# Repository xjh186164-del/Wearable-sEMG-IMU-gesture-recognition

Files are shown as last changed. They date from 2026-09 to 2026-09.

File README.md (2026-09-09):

# Wearable sEMG--IMU Gesture Recognition System

This repository contains the hardware designs, embedded firmware, host
software, accepted recordings and trained model for a battery-powered wearable
gesture-recognition prototype. The system combines eight-channel surface
electromyography (sEMG) with six-axis inertial sensing and transmits both sensor
streams to a host computer using Bluetooth Low Energy (BLE).

The project was developed as an engineering research prototype. It is not a
medical device and must not be used for diagnosis, clinical monitoring or
safety-critical control.

## System overview

The wearable system consists of:

- a custom four-layer ADS1298-based acquisition PCB;
- an LSM6DSOX three-axis accelerometer and three-axis gyroscope;
- an ESP32-C3 microcontroller and BLE link;
- eight bipolar electrode modules and a separate right-leg-drive electrode;
- independently adjustable electrode, right-leg-drive and electronics straps;
- a rechargeable LP603449 lithium-polymer battery;
- MATLAB acquisition, filtering, visualisation and recording software;
- a Python dual-branch convolutional neural network for real-time recognition.

The production firmware samples sEMG at 500 Hz and the IMU at 104 Hz. MATLAB
constructs temporally corresponding 0.5 s windows, and the Python model combines
the two sensor modalities using class-dependent trainable late fusion.

## Reported results

Twenty-one accepted guided-recording sessions provided approximately 62.98
minutes of simultaneous sensor data. The derived dataset contains 12,936 paired
windows representing eight classes. A session-level split assigned 14 sessions
to training, three to validation and four to held-out testing.

On 2,464 held-out test windows, the selected personalised model achieved:

| Metric | Result |
|---|---:|
| Accuracy | 99.68% |
| Balanced accuracy | 99.55% |
| Macro-F1 | 99.64% |

A controlled ablation study subsequently retrained five model variants using
the same session split and three fixed random seeds (20260821--20260823):

| Model variant | Test Macro-F1, mean +/- SD | Target-trial accuracy |
|---|---:|---:|
| sEMG only | 85.33 +/- 2.89% | 91.67% |
| IMU only | 94.09 +/- 0.96% | 98.21% |
| Fixed 50:50 fusion | 99.64 +/- 0.34% | 100.00% |
| Trainable fusion, neutral initialisation | 99.65 +/- 0.32% | 100.00% |
| Trainable fusion, physics-informed initialisation | 99.67 +/- 0.03% | 100.00% |

The experiment verifies the benefit of combining the two modalities for this
gesture set. It does not establish a meaningful accuracy advantage of learned
class-dependent fusion over fixed 50:50 fusion on this dataset. The
physics-informed initialisation is therefore treated as an optimisation prior,
not as evidence that the model independently discovered sensor importance.

These measurements demonstrate personalised recognition for one physical
participant under the tested conditions. They do not establish equivalent
performance for unseen users, alternative electrode placements or uncontrolled
operating environments. Successive 0.5 s evaluation windows advance by 0.1 s,
so the aggregate window predictions overlap by 80% and are not independent
trials; session-level and target-trial results are included alongside them.

## Repository structure

```text
.
├── Hardware/
│   ├── Enclosure and Armband/     # Editable Fusion 360 mechanical designs
│   └── Schematic and PCB/         # EasyEDA project, schematic, BOM/CPL and Gerber archive
├── Software/
│   ├── Firmware/                  # Production ESP32-C3 firmware only
│   ├── MATLAB/                    # BLE acquisition, filtering and live display
│   ├── Python/                    # Dataset, training and inference package
│   └── README.md
├── Data/
│   ├── captures/                  # 21 accepted six-artifact sessions
│   ├── datasets/                  # Paired 0.5 s window dataset and manifest
│   ├── training_runs/             # Selected checkpoint and controlled ablations
│   ├── realtime_configs/          # Validation-selected decision configuration
│   ├── checksums.sha256
│   └── README.md
├── .gitattributes
├── .gitignore
└── README.md
```

Detailed software instructions are provided in
[`Software/README.md`](Software/README.md). Dataset structure, participant
scope, session splitting and artifact descriptions are provided in
[`Data/README.md`](Data/README.md).

## Hardware files

`Hardware/Schematic and PCB` contains the editable EasyEDA Pro project, the
complete schematic image, the manufacturing BOM/CPL and a Gerber archive. The
mechanical directory contains the editable Fusion 360 designs for the electrode
strap, right-leg-drive strap, PCB strap, enclosure and lid.

The editable source files are retained in addition to manufacturing or preview
exports so that later revisions can be traced to the submitted design.

## Software quick start

### 1. Clone the repository with Git LFS

Large measurements and binary design files are tracked using Git Large File
Storage. Install Git LFS before cloning or pulling the complete repository:

```powershell
git lfs install
git clone <repository-url>
cd <repository-directory>
git lfs pull
```

### 2. Flash the wearable firmware

Open the following sketch in the Arduino IDE:

```text
Software/Firmware/esp32c3_ads1298_rld_csv/esp32c3_ads1298_rld_csv.ino
```

Select `ESP32C3 Dev Module`, enable `USB CDC On Boot`, and compile using the
Espressif ESP32 Arduino core. Keep the `.ino`, `.cpp` and `.h` files in the same
sketch directory.

### 3. Prepare the Python environment

The machine-learning software was developed with Python 3.12. From the
repository root:

```powershell
py -3.12 -m venv .venv-gesture
.\.venv-gesture\Scripts\python.exe -m pip install --upgrade pip
.\.venv-gesture\Scripts\python.exe -m pip install -r .\Software\Python\requirements-data.txt
.\.venv-gesture\Scripts\python.exe -m pip install -r .\Software\Python\requirements-cuda.txt
.\.venv-gesture\Scripts\python.exe -m pip install -e .\Software\Python
```

The CUDA requirements reproduce the PyTorch configuration used during model
training. A different compatible PyTorch build may be required on other
hardware.

### 4. Run MATLAB acquisition

Start MATLAB from the repository root and add the acquisition code to the path:

```matlab
repositoryRoot = pwd;
addpath(fullfile(repositoryRoot, "Software", "MATLAB"));
blelist
[rawFile, filteredFile, imuFile] = ...
    ads1298_emg_ble_live("SensorBiShe-EMG", 10);
```

Refer to the Software README for guided acquisition, model training and live
recognition examples.

## Data integrity and reproducibility

`Data/checksums.sha256` contains a SHA-256 digest for every distributed data or
model artifact and for the Data README. The dataset manifest records the source
hashes and window-generation parameters. The model split file independently
records the dataset and manifest hashes, while the real-time configuration
records the selected checkpoint hash. The ablation directory retains the
per-seed checkpoints, histories, predictions, grouped metrics and aggregate
summaries used for the comparison above.

The published capture set contains only the 21 sessions accepted by the
automated quality gate. Informal demonstrations, failed attempts, quarantined
recordings and the rejected session `S003_D07_R02` are intentionally excluded.

## Participant and data-use notice

The acquisition identifiers `S001`, `S002` and `S003` all refer to the same
physical participant and map to canonical identifier `P001`. The recordings
are pseudonymised rather than guaranteed anonymous and include session
timestamps and technical metadata. Confirm participant consent, institutional
requirements, data ownership and an appropriate data licence before making the
repository public or redistributing the measurements.

## Safety notice

When electrodes are attached to a person, power the wearable system from its
battery and disconnect USB. Do not connect the wearer through unisolated USB,
an oscilloscope, a bench supply or other mains-powered equipment. Inspect the
battery, cables, electrodes and enclosure before use and stop immediately if
the wearer experiences discomfort, skin irritation or unusual heating.

## Licence

No software, hardware or data licence has yet been assigned in this repository.
A suitable licence should be selected only after the project ownership and
institutional release conditions have been confirmed.

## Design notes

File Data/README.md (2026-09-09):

# Data, trained models and evaluation results

This directory contains the accepted recordings, derived window dataset,
selected model checkpoint, controlled ablation study and real-time decision
configuration used to produce the results reported for the wearable sEMG--IMU
gesture-recognition system.

## Important participant note

The dataset contains recordings from **one physical participant**. Acquisition
identifiers `S001`, `S002` and `S003` are legacy session aliases and all map to
the canonical participant identifier `P001`; they must not be interpreted as
three different participants. The reported results therefore represent
personalised, session-separated recognition rather than participant-independent
validation.

The files use pseudonymous identifiers and contain no participant name or
email address. They still contain recording timestamps and study metadata and
must therefore not be treated as fully anonymous. Confirm the applicable
consent, institutional and data-protection requirements before making this
directory public.

## Directory structure

```text
Data/
├── captures/                     # 21 accepted guided-recording sessions
├── datasets/
│   ├── p001_windows.npz
│   └── p001_windows.manifest.json
├── training_runs/
│   ├── p001_dual_cnn/
│   │   ├── best_model.pt
│   │   ├── history.csv
│   │   ├── metrics.json
│   │   └── split.json
│   └── p001_ablation_20260908/  # Five variants, three seeds and post-hoc results
├── realtime_configs/
│   ├── p001_dual_cnn_endpoint_v2.json
│   └── p001_dual_cnn_endpoint_v2.test_evaluation.json
├── checksums.sha256
└── README.md
```

## Accepted recording sessions

The `captures` directory contains 21 sessions that passed the automated
`gesture_session_quality_v4` quality gate. Together they contain approximately
62.98 minutes of simultaneous eight-channel sEMG and six-axis IMU data. The
nominal sampling rates are 500 Hz for sEMG and 104 Hz for the accelerometer and
gyroscope.

Each accepted session has exactly six files sharing the same session basename:

| Suffix | Contents |
|---|---|
| `_raw.csv` | ADS1298 samples in raw ADC codes, device timestamps, status and dropped-sample counter |
| `_filtered.csv` | Eight digitally filtered sEMG channels in mV |
| `_imu.csv` | Acceleration in g, angular velocity in degrees/s and temperature in degrees Celsius |
| `_events.csv` | Gesture-protocol events and authoritative temporal labels |
| `_metadata.json` | Acquisition settings, session identity and protocol information |
| `_quality.json` | Sampling, continuity, clipping, IMU plausibility and event-coverage checks |

In session identifiers such as `S003_D08_R02`, `Dxx` denotes the acquisition
date index and `Rxx` denotes a complete removal and refitting performed on that
date. The accepted data therefore include multiple dates and repeated donning
cycles for the same physical participant.

The principal CSV schemas are:

```text
sample,timestamp_us,status,ch1_raw,...,ch8_raw,dropped
sample,timestamp_us,status,ch1_filtered_mV,...,ch8_filtered_mV,dropped
sample,timestamp_us,ax_g,ay_g,az_g,gx_dps,gy_dps,gz_dps,temp_C,dropped
session_time_s,event_type,block_id,trial_id,gesture_id,valid,note
```

The recording protocol contains the following eight classes in their fixed
model order:

```text
REST
WRIST_UP
WRIST_DOWN
FOREARM_IN
FOREARM_OUT
ARM_UP
ARM_DOWN
FIST
```

## Derived window dataset

`datasets/p001_windows.npz` contains 12,936 paired windows generated from the
21 accepted sessions. Each window covers 0.5 s and successive candidate
windows are separated by 0.1 s. The stored input shapes are:

- sEMG: `8 x 250` samples;
- IMU: `6 x 52` samples.

Only windows fully contained within guarded stable intervals are retained.
Movement, return transitions, invalid trials, sequence gaps and windows that
cross label boundaries are excluded. The accompanying manifest records the
accepted sessions, rejected sessions, subject aliases, class counts, source
file SHA-256 values and dataset-generation parameters.

The session-level split used for the reported experiment is:

| Subset | Sessions | Windows |
|---|---:|---:|
| Training | 14 | 8,624 |
| Validation | 3 | 1,848 |
| Test | 4 | 2,464 |

The training subset contains 4,704 REST windows and 1,176 windows for each of
the seven active gestures. Normalisation parameters were calculated from the
training sessions only.

## Trained model artifacts

`training_runs/p001_dual_cnn` contains the selected class-dependent fusion
model and the records needed to interpret it:

- `best_model.pt`: selected PyTorch checkpoint;
- `history.csv`: epoch-by-epoch training loss, validation loss and validation
  Macro-F1;
- `metrics.json`: validation/test metrics, per-class results, confusion
  matrices and learned fusion weights;
- `split.json`: exact session partition and dataset/checksum linkage.

The selected checkpoint was obtained at epoch 8. On the four held-out test
sessions it achieved 99.68% accuracy, 99.55% balanced accuracy and 99.64%
Macro-F1.

## Controlled modality and fusion ablation

`training_runs/p001_ablation_20260908` contains a post-hoc diagnostic of the
selected checkpoint and an independently trained comparison using three fixed
random seeds. All variants use the same dataset and session-level split.

| Retrained variant | Parameters | Accuracy, mean +/- SD | Macro-F1, mean +/- SD | Target trials |
|---|---:|---:|---:|---:|
| sEMG only | 59,080 | 84.97 +/- 2.53% | 85.33 +/- 2.89% | 154/168 |
| IMU only | 21,416 | 95.08 +/- 0.81% | 94.09 +/- 0.96% | 165/168 |
| Fixed 50:50 fusion | 80,496 | 99.68 +/- 0.25% | 99.64 +/- 0.34% | 168/168 |
| Learned fusion, neutral start | 80,504 | 99.69 +/- 0.23% | 99.65 +/- 0.32% | 168/168 |
| Learned fusion, physics-informed start | 80,504 | 99.70 +/- 0.02% | 99.67 +/- 0.03% | 168/168 |

The three-seed results support multimodal fusion over either isolated sensor
branch. The differences among the three fused configurations are small and do
not demonstrate that trainable class-dependent fusion is superior to fixed
50:50 fusion on this dataset. Neutral initialisation also produced high fused
performance without converging to the physics-informed weight pattern.

The four heads of the original selected checkpoint were also evaluated without
retraining. Their test Macro-F1 scores were 83.86% for the sEMG head, 91.50%
for the IMU head, 99.43% for fixed 50:50 fusion and 99.64% for its learned
fusion. These are diagnostic outputs of one jointly trained checkpoint and
must not be treated as a controlled comparison; the independently retrained
results above provide that comparison.

The result directory contains all 15 selected checkpoints together with their
histories, exact splits, window predictions, per-session and target-trial
metrics. `aggregate_summary.csv` is the concise cross-seed result table,
`run_summary.csv` contains one row per training run, and
`ablation_results.json` retains the complete machine-readable evaluation.

Successive test windows overlap by 80%, so the 2,464 window predictions are not
independent observations. The grouped files report results for each held-out
session and for the 56 target trials in every run.

## Real-time configuration

`realtime_configs/p001_dual_cnn_endpoint_v2.json` stores the
validation-selected post-processing configuration used by the live MATLAB and
Python pipeline. It uses an exponential moving average weight of 0.4 for the
new probability vector, a confidence threshold of 0.50 and two consecutive
matching outputs. The test-evaluation JSON records the corresponding held-out
replay results.

## Excluded material

This release intentionally excludes:

- informal BLE checks and live-recognition demonstrations;
- zero-length or interrupted capture attempts;
- session `S003_D07_R02`, which did not pass the quality gate;
- the separate `quarantine` directory containing early, failed or superseded
  recordings.

These files were not used to train, validate or test the selected model and
are omitted to prevent them from being mistaken for accepted experimental
data.

## Integrity and storage

`checksums.sha256` records the SHA-256 digest of every distributed file except
the checksum file itself. Because the capture CSVs, NPZ dataset and PyTorch
checkpoints are large data or binary files, they are tracked with Git Large
File Storage rather than ordinary Git history.

No data-reuse licence is granted by this README. Add an explicit repository
data licence only after ownership, participant consent and institutional
release conditions have been confirmed.

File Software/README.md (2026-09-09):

# Software

This directory contains the software used by the battery-powered wearable
surface-electromyography (sEMG) and inertial-measurement-unit (IMU) gesture
recognition system. It includes the production embedded firmware, the MATLAB
acquisition and visualisation software, and the Python machine-learning
pipeline.

## Directory structure

```text
Software/
├── Firmware/
│   └── esp32c3_ads1298_rld_csv/
│       ├── esp32c3_ads1298_rld_csv.ino
│       ├── lsm6dsox_spi.cpp
│       └── lsm6dsox_spi.h
├── MATLAB/
│   ├── +gesture_internal/
│   ├── gesture_media/
│   └── *.m
├── Python/
│   ├── gesture_ml/
│   │   ├── ablation.py
│   │   ├── variants.py
│   │   └── ...
│   ├── pyproject.toml
│   ├── requirements-data.txt
│   ├── requirements-cuda.txt
│   ├── uv.lock
│   └── verify_cuda.py
└── README.md
```

## System software flow

1. The ESP32-C3 firmware samples eight ADS1298 channels at 500 samples/s and
   the LSM6DSOX accelerometer and gyroscope at 104 samples/s.
2. Device timestamps, sequence numbers and dropped-sample counters are added
   before the measurements are transmitted using the version 2 binary BLE
   protocol.
3. MATLAB receives and decodes the BLE notifications, filters and displays the
   sEMG signals, displays the IMU measurements, and writes recording files.
4. For real-time recognition, MATLAB sends paired 0.5 s sensor windows to a
   persistent local Python worker over TCP.
5. Python applies the saved normalisation parameters, evaluates the trained
   dual-branch convolutional neural network, and returns class probabilities to
   MATLAB.

## 1. Embedded firmware

The production sketch is located at:

```text
Firmware/esp32c3_ads1298_rld_csv/esp32c3_ads1298_rld_csv.ino
```

It configures:

- ADS1298: eight channels, 500 samples/s, gain 6 and right-leg-drive enabled;
- LSM6DSOX accelerometer: 104 Hz and +/-4 g;
- LSM6DSOX gyroscope: 104 Hz and +/-500 degrees/s;
- BLE device name: `SensorBiShe-EMG`;
- BLE protocol version: 2;
- requested BLE MTU: 247 bytes.

Open the `.ino` file in the Arduino IDE with all three firmware files in the
same sketch directory. Select `ESP32C3 Dev Module` and enable `USB CDC On
Boot`, then compile and upload the sketch using the Espressif ESP32 Arduino
core. USB is used for programming and startup diagnostics; measurement samples
are transmitted through BLE during normal operation.

## 2. MATLAB acquisition and live recognition

The principal MATLAB entry points are:

- `ads1298_emg_ble_live`: BLE acquisition, filtering, visualisation and file
  recording;
- `gesture_guided_acquisition`: video-guided labelled-session acquisition;
- `gesture_live_recognition`: acquisition with live Python model inference.

From the repository root, add the MATLAB directory to the search path:

```matlab
repositoryRoot = pwd;
addpath(fullfile(repositoryRoot, "Software", "MATLAB"));
```

To verify that the wearable device is visible and run a short BLE acquisition:

```matlab
blelist
[rawFile, filteredFile, imuFile] = ...
    ads1298_emg_ble_live("SensorBiShe-EMG", 10);
```

For a guided recording, supply an anonymous subject identifier and an explicit
output directory. The following directory names are examples and can be
adapted to the final repository data layout:

```matlab
config = struct( ...
    "SubjectId", "S001", ...
    "SessionId", "S001_D01_R01", ...
    "OperatorCode", "OperatorCode01", ...
    "SleeveSize", "CUSTOM_V1", ...
    "ArmSide", "left", ...
    "BlockCount", 2, ...
    "CaptureDirectory", fullfile(repositoryRoot, "Data", "captures"));

result = gesture_guided_acquisition(config);
disp(result.quality);
```

The MATLAB code requires access to the `ble` and `blelist` interfaces and to
the signal-processing functions used by the digital filter implementation.

## 3. Python machine-learning pipeline

The Python package supports:

- construction of timestamp-aligned sEMG--IMU datasets;
- session-level training, validation and test partitioning;
- training and evaluation of the dual-branch convolutional neural network;
- post-hoc branch evaluation and controlled retraining of five ablation
  variants;
- calibration and replay of the real-time decision filter;
- persistent TCP inference for the MATLAB client.

The software was developed using Python 3.12. Create a virtual environment
outside the tracked source directories and install the package from the
repository root:

```powershell
py -3.12 -m venv .venv-gesture
.\.venv-gesture\Scripts\python.exe -m pip install --upgrade pip
.\.venv-gesture\Scripts\python.exe -m pip install -r .\Software\Python\requirements-data.txt
.\.venv-gesture\Scripts\python.exe -m pip install -r .\Software\Python\requirements-cuda.txt
.\.venv-gesture\Scripts\python.exe -m pip install -e .\Software\Python
```

`requirements-cuda.txt` pins the PyTorch configuration used for GPU training.
Users who do not need to reproduce the original CUDA environment may install a
PyTorch build suitable for their own operating system and hardware.

An example dataset-build command is:

```powershell
.\.venv-gesture\Scripts\gesture-build-dataset.exe `
  --captures .\Data\captures `
  --output .\Data\datasets\p001_windows.npz
```

An example training command is:

```powershell
.\.venv-gesture\Scripts\gesture-train.exe `
  --dataset .\Data\datasets\p001_windows.npz `
  --output-dir .\Data\training_runs\p001_dual_cnn `
  --seed 20260821
```

To reproduce the additional modality and fusion comparison, run:

```powershell
.\.venv-gesture\Scripts\gesture-ablation.exe `
  --dataset .\Data\datasets\p001_windows.npz `
  --baseline-checkpoint .\Data\training_runs\p001_dual_cnn\best_model.pt `
  --output-dir .\Data\training_runs\p001_ablation_reproduction `
  --device cuda `
  --seeds 20260821,20260822,20260823
```

The command first evaluates the existing selected checkpoint with its sEMG
head, IMU head, fixed 50:50 fusion and learned fusion. It then independently
trains `emg_only`, `imu_only`, `fixed_50_50`, `learned_neutral` and
`learned_physics` variants for each seed. Each run stores its selected
checkpoint, epoch history, exact split, window-level predictions and grouped
session/trial metrics. Aggregate outputs are written to
`aggregate_summary.csv`, `run_summary.csv` and `ablation_results.json`.

The published run is retained under
`Data/training_runs/p001_ablation_20260908`. Reproduction results should be
written to a different directory, as in the example, to avoid overwriting the
reported artifacts.

## 4. Live recognition

Live recognition requires a trained checkpoint and the selected real-time
calibration file. These binary/data artifacts are not stored in this Software
directory. Pass their final locations explicitly when they are placed in the
repository Data directory:

```matlab
config = struct( ...
    "DurationSeconds", 60, ...
    "OutputDirectory", fullfile(repositoryRoot, "Data", "captures"), ...
    "CheckpointPath", fullfile(repositoryRoot, "Data", ...
        "training_runs", "p001_dual_cnn", "best_model.pt"), ...
    "CalibrationPath", fullfile(repositoryRoot, "Data", ...
        "realtime_configs", "p001_dual_cnn_endpoint_v2.json"), ...
    "PythonExecutable", fullfile(repositoryRoot, ...
        ".venv-gesture", "Scripts", "python.exe"));

result = gesture_live_recognition(config);
disp(result.recognitionSummary);
```

## Safety notice

This system is an engineering research prototype and is not a medical device.
When electrodes are attached to a person, operate the wearable electronics
from the battery and disconnect the USB cable. Do not create a conductive path
from the wearer to a non-isolated computer, bench supply, oscilloscope or other
mains-powered equipment.

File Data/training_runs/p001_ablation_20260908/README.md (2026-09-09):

# Controlled modality and fusion ablation

This directory contains the additional experiment used to determine how much
performance came from sEMG, IMU and multimodal fusion. It also tests whether
trainable class-dependent fusion improves upon fixed 50:50 fusion and whether
physics-informed initial weights are necessary.

## Experiment design

All retrained variants use the published `p001_windows.npz` dataset, the same
session-level training/validation/test split, and the three fixed seeds
20260821, 20260822 and 20260823. The five variants are:

- `emg_only`: sEMG encoder and classifier only;
- `imu_only`: IMU encoder and classifier only;
- `fixed_50_50`: both branches with fixed equal logit fusion;
- `learned_neutral`: trainable class weights initialised to 0.5;
- `learned_physics`: trainable class weights initialised using the expected
  physical contribution of the two modalities.

## Aggregate held-out results

| Variant | Macro-F1, mean +/- SD | Mean session Macro-F1 | Target-trial accuracy |
|---|---:|---:|---:|
| sEMG only | 85.33 +/- 2.89% | 85.57% | 91.67% |
| IMU only | 94.09 +/- 0.96% | 94.03% | 98.21% |
| Fixed 50:50 fusion | 99.64 +/- 0.34% | 99.63% | 100.00% |
| Learned fusion, neutral start | 99.65 +/- 0.32% | 99.65% | 100.00% |
| Learned fusion, physics-informed start | 99.67 +/- 0.03% | 99.66% | 100.00% |

Multimodal fusion substantially outperformed either isolated branch. The three
fused variants performed similarly, so these data do not establish a material
accuracy advantage for learned fusion over fixed equal fusion. The lower
cross-seed variability of the physics-informed runs is limited evidence from
three repetitions and should not be generalised beyond this experiment.

## Files

- `aggregate_summary.csv`: mean and sample standard deviation across seeds;
- `run_summary.csv`: one concise row for each of the 15 retraining runs;
- `ablation_results.json`: complete post-hoc and retraining results;
- `posthoc_existing_checkpoint/`: diagnostic branch/fusion evaluation of the
  original selected checkpoint;
- `retrained/<variant>/seed_<seed>/best_model.pt`: selected checkpoint;
- `history.csv`: epoch-by-epoch training and validation history;
- `metrics.json`: validation and held-out window metrics;
- `grouped_test_metrics.json`: per-session and target-trial results;
- `test_predictions.csv`: held-out window predictions;
- `split.json`: exact session split and dataset linkage.

The 0.5 s test windows advance by 0.1 s and therefore overlap by 80%.
Window-level predictions are not independent trials; use the grouped session
and target-trial metrics when interpreting robustness.

## Reproduction command

From the repository root after installing the Python package:

```powershell
.\.venv-gesture\Scripts\gesture-ablation.exe `
  --dataset .\Data\datasets\p001_windows.npz `
  --baseline-checkpoint .\Data\training_runs\p001_dual_cnn\best_model.pt `
  --output-dir .\Data\training_runs\p001_ablation_reproduction `
  --device cuda `
  --seeds 20260821,20260822,20260823
```

Use a new output directory so that the published results are not overwritten.

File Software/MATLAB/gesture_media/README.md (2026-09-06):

# Authoritative gesture demonstration media

This directory contains the eight approved demonstration videos derived from
reviewed human recordings. The approved bytes were produced and audited during
v3 and are reused byte-for-byte by `eight_pose_v5`; this protocol-only upgrade
requires no re-recording and no re-encoding. Do not replace them with synthetic
motion, placeholder, or test media.

An approved recording session must provide these exact files:

- `REST.mp4`
- `WRIST_UP.mp4`
- `WRIST_DOWN.mp4`
- `FOREARM_IN.mp4`
- `FOREARM_OUT.mp4`
- `ARM_UP.mp4`
- `ARM_DOWN.mp4`
- `FIST.mp4`

Each installed file is a silent H.264 MP4 in landscape orientation at
1280×720, 30 fps, 255 frames, and approximately 8.5 seconds. The exact target
timeline is `READY` from 0-1 s, `MOVE` from 1-2.5 s, `HOLD STILL` from
2.5-6.5 s, and `RETURN TO REST` from 6.5-8.5 s. The target endpoint must remain
stable throughout `HOLD STILL`; during that stage, `ARM_DOWN.mp4` must visibly
point toward the floor rather than horizontally. The final segment must show
the participant returning to the horizontal neutral pose.

`REST.mp4` shows `READY` from 0-1 s and a horizontal, wrist-neutral, relaxed
pose labelled `HOLD: RELAX` from 1-8.5 s. The acquisition program uses the
first two seconds of a rest presentation for each 2 s relaxed hold.

`FIST.mp4` must begin with the forearm horizontal, wrist neutral, and fingers
relaxed; close to a complete fist during `MOVE`, with the thumb outside the
four fingers; hold the endpoint for the complete 4 s `HOLD STILL` stage without
wrist, forearm, or arm movement; then return to the relaxed pose.

`gesture_video_manifest.csv` records the v3-produced stage endpoints and duration.
`output_hashes_sha256_v3.csv` records the SHA-256 digest of every installed
MP4 and is the integrity reference for preflight checks and the protocol
freeze.

The automated MATLAB tests create synthetic MP4 fixtures in temporary
directories and never use this production directory.

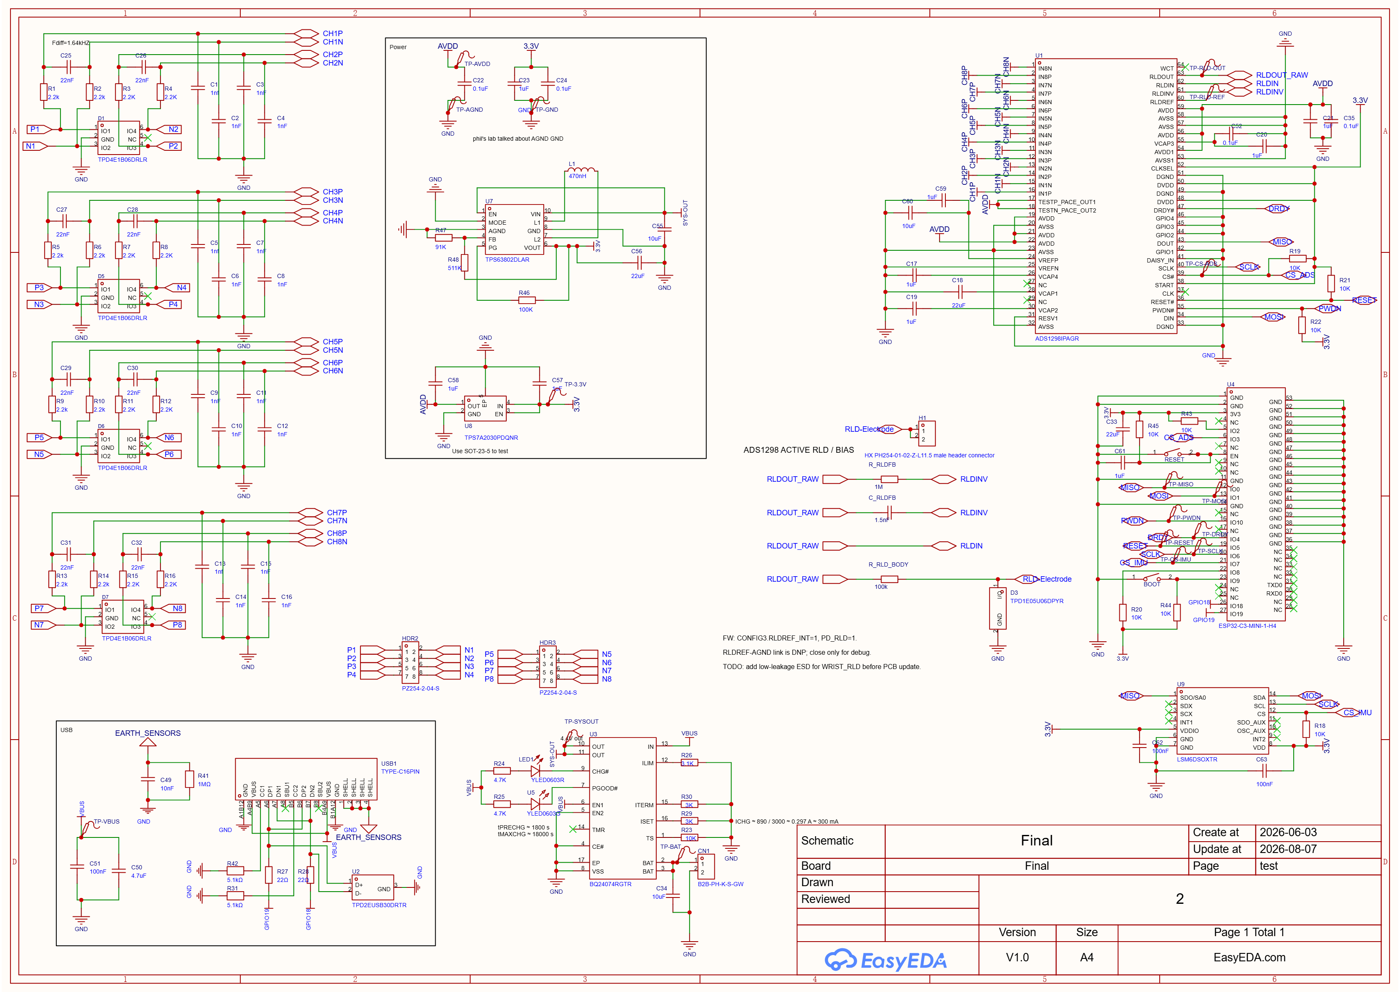
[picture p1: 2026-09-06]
Hardware/Schematic and PCB/Schematic.png

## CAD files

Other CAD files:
Hardware/Enclosure and Armband/Electrode-strap and Extension.f3d
Hardware/Enclosure and Armband/PCB and Battery Enclosure and Lid.f3d
Hardware/Enclosure and Armband/PCB-Strap.f3d
Hardware/Enclosure and Armband/RLD-strap.f3d

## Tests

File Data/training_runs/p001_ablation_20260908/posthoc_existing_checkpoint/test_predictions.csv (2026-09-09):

dataset_index | session_id | trial_id | true_index | true_label | emg_only_index | emg_only_label | imu_only_index | imu_only_label | fixed_50_50_index | fixed_50_50_label | learned_fusion_index | learned_fusion_label
10472 | S003_D08_R01 | 1 | 0 | REST | 6 | ARM_DOWN | 0 | REST | 0 | REST | 0 | REST
10473 | S003_D08_R01 | 1 | 0 | REST | 6 | ARM_DOWN | 0 | REST | 0 | REST | 0 | REST
10474 | S003_D08_R01 | 1 | 0 | REST | 6 | ARM_DOWN | 0 | REST | 0 | REST | 0 | REST
10475 | S003_D08_R01 | 1 | 0 | REST | 6 | ARM_DOWN | 0 | REST | 0 | REST | 0 | REST
10476 | S003_D08_R01 | 1 | 0 | REST | 6 | ARM_DOWN | 0 | REST | 0 | REST | 0 | REST
10477 | S003_D08_R01 | 1 | 0 | REST | 6 | ARM_DOWN | 0 | REST | 0 | REST | 0 | REST
10478 | S003_D08_R01 | 1 | 0 | REST | 6 | ARM_DOWN | 0 | REST | 0 | REST | 0 | REST
10479 | S003_D08_R01 | 1 | 0 | REST | 6 | ARM_DOWN | 0 | REST | 0 | REST | 0 | REST
10480 | S003_D08_R01 | 1 | 6 | ARM_DOWN | 6 | ARM_DOWN | 6 | ARM_DOWN | 6 | ARM_DOWN | 6 | ARM_DOWN
10481 | S003_D08_R01 | 1 | 6 | ARM_DOWN | 6 | ARM_DOWN | 6 | ARM_DOWN | 6 | ARM_DOWN | 6 | ARM_DOWN
10482 | S003_D08_R01 | 1 | 6 | ARM_DOWN | 6 | ARM_DOWN | 6 | ARM_DOWN | 6 | ARM_DOWN | 6 | ARM_DOWN
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

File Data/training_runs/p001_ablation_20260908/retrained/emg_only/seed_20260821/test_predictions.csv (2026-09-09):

dataset_index | session_id | trial_id | true_index | true_label | emg_only_index | emg_only_label
10472 | S003_D08_R01 | 1 | 0 | REST | 6 | ARM_DOWN
10473 | S003_D08_R01 | 1 | 0 | REST | 6 | ARM_DOWN
10474 | S003_D08_R01 | 1 | 0 | REST | 6 | ARM_DOWN
10475 | S003_D08_R01 | 1 | 0 | REST | 6 | ARM_DOWN
10476 | S003_D08_R01 | 1 | 0 | REST | 6 | ARM_DOWN
10477 | S003_D08_R01 | 1 | 0 | REST | 6 | ARM_DOWN
10478 | S003_D08_R01 | 1 | 0 | REST | 6 | ARM_DOWN
10479 | S003_D08_R01 | 1 | 0 | REST | 6 | ARM_DOWN
10480 | S003_D08_R01 | 1 | 6 | ARM_DOWN | 6 | ARM_DOWN
10481 | S003_D08_R01 | 1 | 6 | ARM_DOWN | 6 | ARM_DOWN
10482 | S003_D08_R01 | 1 | 6 | ARM_DOWN | 6 | ARM_DOWN
10483 | S003_D08_R01 | 1 | 6 | ARM_DOWN | 6 | ARM_DOWN
10484 | S003_D08_R01 | 1 | 6 | ARM_DOWN | 6 | ARM_DOWN
10485 | S003_D08_R01 | 1 | 6 | ARM_DOWN | 6 | ARM_DOWN
10486 | S003_D08_R01 | 1 | 6 | ARM_DOWN | 6 | ARM_DOWN
10487 | S003_D08_R01 | 1 | 6 | ARM_DOWN | 6 | ARM_DOWN
10488 | S003_D08_R01 | 1 | 6 | ARM_DOWN | 6 | ARM_DOWN
10489 | S003_D08_R01 | 1 | 6 | ARM_DOWN | 6 | ARM_DOWN
10490 | S003_D08_R01 | 1 | 6 | ARM_DOWN | 6 | ARM_DOWN
10491 | S003_D08_R01 | 1 | 6 | ARM_DOWN | 6 | ARM_DOWN
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

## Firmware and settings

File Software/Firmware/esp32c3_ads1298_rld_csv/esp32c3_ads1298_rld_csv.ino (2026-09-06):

// ESP32-C3-MINI-1-H4 <-> ADS1298 + LSM6DSOX BLE binary streamer with RLD.
// Select ESP32C3 Dev Module with USB CDC On Boot enabled.

#include <Arduino.h>
#include <BLE2902.h>
#include <BLEDevice.h>
#include <BLEServer.h>
#include <BLEUtils.h>
#include <SPI.h>

#include "lsm6dsox_spi.h"

constexpr uint8_t PIN_MOSI = 1;     // U4 pad 13, GPIO1 -> ADS DIN
constexpr uint8_t PIN_MISO = 0;     // U4 pad 12, GPIO0 <- ADS DOUT
constexpr uint8_t PIN_CS_IMU = 7;   // U4 pad 21, GPIO7
constexpr uint8_t PIN_DRDY = 4;
constexpr uint8_t PIN_RESET = 5;
constexpr uint8_t PIN_CS_ADS = 3;   // U4 pad 6, GPIO3
constexpr uint8_t PIN_SCLK = 6;     // U4 pad 20, GPIO6
constexpr uint8_t PIN_PWDN = 10;

constexpr uint8_t CMD_START = 0x08;
constexpr uint8_t CMD_RDATAC = 0x10;
constexpr uint8_t CMD_SDATAC = 0x11;
constexpr uint8_t CMD_RREG = 0x20;
constexpr uint8_t CMD_WREG = 0x40;

constexpr uint8_t REG_ID = 0x00;
constexpr uint8_t REG_CONFIG1 = 0x01;
constexpr uint8_t REG_CONFIG2 = 0x02;
constexpr uint8_t REG_CONFIG3 = 0x03;
constexpr uint8_t REG_CH1SET = 0x05;
constexpr uint8_t REG_RLD_SENSP = 0x0D;
constexpr uint8_t REG_RLD_SENSN = 0x0E;

constexpr uint8_t ADS1298_ID = 0x92;
constexpr uint8_t CONFIG1_500_SPS_HR = 0x86;
constexpr uint8_t CONFIG2_TEST_OFF = 0x00;
constexpr uint8_t CONFIG3_RLD_ON_INTERNAL_REF = 0xCC;
constexpr uint8_t CHANNEL_NORMAL_GAIN6 = 0x00;
constexpr uint8_t RLD_SENSP_CH1 = 0x01;
constexpr uint8_t RLD_SENSN_CH1 = 0x01;

constexpr uint8_t ADS_FRAME_BYTES = 27;
constexpr uint8_t ADS_CHANNEL_COUNT = 8;
constexpr size_t SAMPLE_QUEUE_CAPACITY = 128;
constexpr size_t IMU_QUEUE_CAPACITY = 32;

constexpr char BLE_DEVICE_NAME[] = "SensorBiShe-EMG";
constexpr char BLE_SERVICE_UUID[] =
    "7b1e0001-6f9b-4c3d-8a6e-2f4a5b6c7d80";
constexpr char BLE_DATA_CHARACTERISTIC_UUID[] =
    "7b1e0002-6f9b-4c3d-8a6e-2f4a5b6c7d80";
constexpr uint8_t BLE_PACKET_MAGIC_0 = 0xA5;
constexpr uint8_t BLE_PACKET_MAGIC_1 = 0x5A;
constexpr uint8_t BLE_PROTOCOL_VERSION = 2;
constexpr uint8_t BLE_RECORD_TYPE_EMG = 1;
constexpr uint8_t BLE_RECORD_TYPE_IMU = 2;
constexpr size_t BLE_PACKET_HEADER_BYTES = 8;
constexpr size_t EMG_SAMPLE_BYTES = 24;
constexpr size_t IMU_SAMPLE_BYTES = 14;
constexpr size_t EMG_PACKET_METADATA_BYTES = 15;
constexpr size_t IMU_PACKET_METADATA_BYTES = 12;
constexpr size_t BLE_MAX_ATT_PAYLOAD_BYTES = 244;
constexpr uint16_t BLE_REQUESTED_MTU = 247;
constexpr uint32_t EMG_BATCH_WAIT_US = 20000;
constexpr uint32_t IMU_BATCH_WAIT_US = 160000;

SPISettings registerSpi(100000, MSBFIRST, SPI_MODE1);
SPISettings dataSpi(4000000, MSBFIRST, SPI_MODE1);
Lsm6dsoxSpi imu(SPI, PIN_CS_IMU);

struct Sample {
  uint32_t sequence;
  uint32_t timestampUs;
  uint32_t status;
  int32_t channels[ADS_CHANNEL_COUNT];
  uint32_t dropped;
};

struct ImuSample {
  uint32_t sequence;
  uint32_t timestampUs;
  int16_t temperature;
  int16_t gyro[3];
  int16_t acceleration[3];
  uint32_t dropped;
};

QueueHandle_t sampleQueue = nullptr;
QueueHandle_t imuQueue = nullptr;
TaskHandle_t acquisitionTaskHandle = nullptr;

uint32_t nextSequence = 0;
uint32_t droppedSamples = 0;
uint32_t nextImuSequence = 0;
uint32_t droppedImuSamples = 0;
volatile uint32_t acquisitionHeartbeat = 0;
uint32_t lastHeartbeat = 0;
uint32_t lastHeartbeatCheckMs = 0;
bool streaming = false;

BLEServer *bleServer = nullptr;
BLECharacteristic *bleDataCharacteristic = nullptr;
volatile bool bleConnected = false;
volatile bool bleSubscribed = false;
volatile bool bleFlushRequested = false;
volatile uint16_t bleConnectionHandle = BLE_HS_CONN_HANDLE_NONE;
volatile uint16_t blePeerMtu = 23;
uint16_t nextBlePacketSequence = 0;
bool bleMtuErrorReported = false;

class EmgBleServerCallbacks : public BLEServerCallbacks {
  void onConnect(BLEServer *server, ble_gap_conn_desc *description) override {
    bleConnected = true;
    bleSubscribed = false;
    bleFlushRequested = true;
    if (description != nullptr) {
      bleConnectionHandle = description->conn_handle;
      blePeerMtu = server->getPeerMTU(description->conn_handle);
      server->requestConnParams(description->conn_handle, 6, 12, 0, 200);
    }
    Serial.println("# INFO,BLE_CONNECTED");
  }

  void onDisconnect(BLEServer *server, ble_gap_conn_desc *description) override {
    (void)server;
    (void)description;
    bleConnected = false;
    bleSubscribed = false;
    bleConnectionHandle = BLE_HS_CONN_HANDLE_NONE;
    blePeerMtu = 23;
    Serial.println("# INFO,BLE_DISCONNECTED");
    BLEDevice::startAdvertising();
    const bool advertisingActive =
        BLEDevice::getAdvertising()->isAdvertising();
    Serial.printf("# INFO,BLE_ADVERTISING_RESTART,active=%u\r\n",
                  static_cast<unsigned>(advertisingActive));
  }

  void onMtuChanged(BLEServer *server, ble_gap_conn_desc *description,
                    uint16_t mtu) override {
    (void)server;
    (void)description;
    blePeerMtu = mtu;
    Serial.printf("# INFO,BLE_MTU,%u\r\n", static_cast<unsigned>(mtu));
  }
};

class EmgBleDataCallbacks : public BLECharacteristicCallbacks {
  void onSubscribe(BLECharacteristic *characteristic,
                   ble_gap_conn_desc *description,
                   uint16_t subscriptionValue) override {
    (void)characteristic;
    bleSubscribed = (subscriptionValue & 0x0001U) != 0;
    if (description != nullptr) {
      bleConnectionHandle = description->conn_handle;
    }
    if (bleSubscribed) {
      bleFlushRequested = true;
      Serial.println("# INFO,BLE_NOTIFY_ENABLED");
    } else {
      Serial.println("# INFO,BLE_NOTIFY_DISABLED");
    }
  }
};

EmgBleServerCallbacks bleServerCallbacks;
EmgBleDataCallbacks bleDataCallbacks;

int32_t decodeSigned24(const uint8_t *bytes) {
  int32_t value = (static_cast<int32_t>(bytes[0]) << 16) |
                  (static_cast<int32_t>(bytes[1]) << 8) |
                  static_cast<int32_t>(bytes[2]);

  if ((value & 0x00800000L) != 0) {
    value |= 0xFF000000L;
  }
  return value;
}

uint32_t decodeStatus24(const uint8_t *bytes) {
  return (static_cast<uint32_t>(bytes[0]) << 16) |
         (static_cast<uint32_t>(bytes[1]) << 8) |
         static_cast<uint32_t>(bytes[2]);
}

bool runDecoderSelfTest() {
  const uint8_t zero[3] = {0x00, 0x00, 0x00};
  const uint8_t maxPositive[3] = {0x7F, 0xFF, 0xFF};
  const uint8_t minNegative[3] = {0x80, 0x00, 0x00};
  const uint8_t minusOne[3] = {0xFF, 0xFF, 0xFF};
  const uint8_t status[3] = {0xC0, 0x00, 0x00};

  return decodeSigned24(zero) == 0 &&
         decodeSigned24(maxPositive) == 8388607 &&
         decodeSigned24(minNegative) == -8388608 &&
         decodeSigned24(minusOne) == -1 &&
         decodeStatus24(status) == 12582912UL;
}

void ARDUINO_ISR_ATTR onDrdyFalling() {
  if (acquisitionTaskHandle == nullptr) {
    return;
  }

  BaseType_t higherPriorityTaskWoken = pdFALSE;
  vTaskNotifyGiveFromISR(acquisitionTaskHandle, &higherPriorityTaskWoken);
  if (higherPriorityTaskWoken == pdTRUE) {
    portYIELD_FROM_ISR();
  }
}

void adsSelect(uint16_t setupUs = 20) {
  delayMicroseconds(setupUs);
  digitalWrite(PIN_CS_ADS, LOW);
  delayMicroseconds(setupUs);
}

void adsDeselect(uint16_t holdUs = 20, uint16_t recoveryUs = 40) {
  delayMicroseconds(holdUs);
  digitalWrite(PIN_CS_ADS, HIGH);
  delayMicroseconds(recoveryUs);
}

void adsCommand(uint8_t command) {
  SPI.beginTransaction(registerSpi);
  adsSelect();
  SPI.transfer(command);
  adsDeselect();
  SPI.endTransaction();
  delayMicroseconds(80);
}

bool waitForDrdyLow(uint32_t timeoutMs) {
  const uint32_t startMs = millis();
  while (digitalRead(PIN_DRDY) == HIGH) {
    if (millis() - startMs >= timeoutMs) {
      return false;
    }
    delay(1);
  }
  return true;
}

void resetAdsHardware() {
  digitalWrite(PIN_CS_ADS, HIGH);
  digitalWrite(PIN_PWDN, HIGH);
  digitalWrite(PIN_RESET, LOW);
  delay(20);
  digitalWrite(PIN_RESET, HIGH);
  delay(500);
}

void stopContinuousModeRobustly() {
  for (uint8_t attempt = 0; attempt < 10; ++attempt) {
    waitForDrdyLow(20);
    delayMicroseconds(300);
    adsCommand(CMD_SDATAC);
    delay(3);
  }
}

void readRegisters(uint8_t startAddress, uint8_t *buffer, uint8_t count) {
  SPI.beginTransaction(registerSpi);
  adsSelect();
  SPI.transfer(CMD_RREG | (startAddress & 0x1F));
  delayMicroseconds(80);
  SPI.transfer((count - 1) & 0x1F);
  delayMicroseconds(80);

  for (uint8_t i = 0; i < count; ++i) {
    buffer[i] = SPI.transfer(0x00);
  }

  adsDeselect();
  SPI.endTransaction();
}

void writeRegisters(uint8_t startAddress, const uint8_t *data, uint8_t count) {
  SPI.beginTransaction(registerSpi);
  adsSelect();
  SPI.transfer(CMD_WREG | (startAddress & 0x1F));
  delayMicroseconds(80);
  SPI.transfer((count - 1) & 0x1F);
  delayMicroseconds(80);

  for (uint8_t i = 0; i < count; ++i) {
    SPI.transfer(data[i]);
    delayMicroseconds(80);
  }

  adsDeselect();
  SPI.endTransaction();
  delayMicroseconds(80);
}

bool verifyRegister(uint8_t address, uint8_t expected, uint8_t actual) {
  if (actual == expected) {
    return true;
  }

  Serial.printf("# ERROR,CONFIG_VERIFY,address=0x%02X,expected=0x%02X,actual=0x%02X\r\n",
                address, expected, actual);
  return false;
}

bool initializeAds1298() {
  resetAdsHardware();
  stopContinuousModeRobustly();

  uint8_t id = 0;
  readRegisters(REG_ID, &id, 1);
  if (id != ADS1298_ID) {
    Serial.printf("# ERROR,ADS_ID,expected=0x%02X,actual=0x%02X\r\n", ADS1298_ID, id);
    return false;
  }

  const uint8_t configs[3] = {
      CONFIG1_500_SPS_HR,
      CONFIG2_TEST_OFF,
      CONFIG3_RLD_ON_INTERNAL_REF,
  };
  const uint8_t channels[ADS_CHANNEL_COUNT] = {
      CHANNEL_NORMAL_GAIN6, CHANNEL_NORMAL_GAIN6,
      CHANNEL_NORMAL_GAIN6, CHANNEL_NORMAL_GAIN6,
      CHANNEL_NORMAL_GAIN6, CHANNEL_NORMAL_GAIN6,
      CHANNEL_NORMAL_GAIN6, CHANNEL_NORMAL_GAIN6,
  };
  const uint8_t rldSense[2] = {
      RLD_SENSP_CH1,
      RLD_SENSN_CH1,
  };

  writeRegisters(REG_CONFIG1, configs, sizeof(configs));
  writeRegisters(REG_CH1SET, channels, sizeof(channels));
  writeRegisters(REG_RLD_SENSP, rldSense, sizeof(rldSense));
  delay(200);

  uint8_t registers[15] = {0};
  readRegisters(REG_ID, registers, sizeof(registers));

  bool valid = verifyRegister(REG_ID, ADS1298_ID, registers[REG_ID]);
  valid &= verifyRegister(REG_CONFIG1, configs[0], registers[REG_CONFIG1]);
  valid &= verifyRegister(REG_CONFIG2, configs[1], registers[REG_CONFIG2]);
  valid &= verifyRegister(REG_CONFIG3, configs[2], registers[REG_CONFIG3]);
  for (uint8_t channel = 0; channel < ADS_CHANNEL_COUNT; ++channel) {
    const uint8_t address = REG_CH1SET + channel;
    valid &= verifyRegister(address, CHANNEL_NORMAL_GAIN6, registers[address]);
  }
  valid &= verifyRegister(REG_RLD_SENSP, rldSense[0], registers[REG_RLD_SENSP]);
  valid &= verifyRegister(REG_RLD_SENSN, rldSense[1], registers[REG_RLD_SENSN]);
  if (!valid) {
    return false;
  }

  adsCommand(CMD_START);
  delay(10);
  adsCommand(CMD_RDATAC);
  return true;
}

void readDataFrame(uint8_t *frame) {
  SPI.beginTransaction(dataSpi);
  adsSelect(2);
  for (uint8_t i = 0; i < ADS_FRAME_BYTES; ++i) {
    frame[i] = SPI.transfer(0x00);
  }
  adsDeselect(2, 2);
  SPI.endTransaction();
}

void putU16(uint8_t *buffer, size_t &offset, uint16_t value) {
  buffer[offset++] = static_cast<uint8_t>(value & 0xFFU);
  buffer[offset++] = static_cast<uint8_t>((value >> 8) & 0xFFU);
}

void putI16(uint8_t *buffer, size_t &offset, int16_t value) {
  putU16(buffer, offset, static_cast<uint16_t>(value));
}

void putU24(uint8_t *buffer, size_t &offset, uint32_t value) {
  buffer[offset++] = static_cast<uint8_t>(value & 0xFFU);
  buffer[offset++] = static_cast<uint8_t>((value >> 8) & 0xFFU);
  buffer[offset++] = static_cast<uint8_t>((value >> 16) & 0xFFU);
}

void putI24(uint8_t *buffer, size_t &offset, int32_t value) {
  putU24(buffer, offset, static_cast<uint32_t>(value) & 0x00FFFFFFUL);
}

void putU32(uint8_t *buffer, size_t &offset, uint32_t value) {
  buffer[offset++] = static_cast<uint8_t>(value & 0xFFU);
  buffer[offset++] = static_cast<uint8_t>((value >> 8) & 0xFFU);
  buffer[offset++] = static_cast<uint8_t>((value >> 16) & 0xFFU);
  buffer[offset++] = static_cast<uint8_t>((value >> 24) & 0xFFU);
}

bool runBleEncoderSelfTest() {
  uint8_t bytes[16] = {0};
  size_t offset = 0;
  putU16(bytes, offset, 0x1234U);
  putU24(bytes, offset, 0x00C0ABCDUL);
  putI24(bytes, offset, -1);
  putU32(bytes, offset, 0x89ABCDEFUL);
  putI16(bytes, offset, -32768);

  const uint8_t expected[] = {
      0x34, 0x12, 0xCD, 0xAB, 0xC0, 0xFF, 0xFF,
      0xFF, 0xEF, 0xCD, 0xAB, 0x89, 0x00, 0x80,
  };
  if (offset != sizeof(expected)) {
    return false;
  }
  for (size_t index = 0; index < sizeof(expected); ++index) {
    if (bytes[index] != expected[index]) {
      return false;
    }
  }
  return true;
}

void putBleHeader(uint8_t *buffer, uint8_t recordType, uint8_t recordCount,
                  uint8_t recordBytes, uint16_t packetSequence) {
  size_t offset = 0;
  buffer[offset++] = BLE_PACKET_MAGIC_0;
  buffer[offset++] = BLE_PACKET_MAGIC_1;
  buffer[offset++] = BLE_PROTOCOL_VERSION;
  buffer[offset++] = recordType;
  buffer[offset++] = recordCount;
  buffer[offset++] = recordBytes;
  putU16(buffer, offset, packetSequence);
}

size_t currentBlePayloadLimit() {
  if (!bleConnected || bleServer == nullptr ||
      bleConnectionHandle == BLE_HS_CONN_HANDLE_NONE) {
    return 0;
  }

  const uint16_t reportedMtu = bleServer->getPeerMTU(bleConnectionHandle);
  if (reportedMtu >= 23) {
    blePeerMtu = reportedMtu;
  }
  if (blePeerMtu <= 3) {
    return 0;
  }
  const size_t payloadBytes = static_cast<size_t>(blePeerMtu - 3);
  return payloadBytes < BLE_MAX_ATT_PAYLOAD_BYTES
             ? payloadBytes
             : BLE_MAX_ATT_PAYLOAD_BYTES;
}

bool notifyBlePacket(uint8_t *packet, size_t packetBytes) {
  if (!bleConnected || !bleSubscribed || bleDataCharacteristic == nullptr) {
    return false;
  }
  bleDataCharacteristic->setValue(packet, packetBytes);
  bleDataCharacteristic->notify();
  ++nextBlePacketSequence;
  return true;
}

bool drainOneBleEmgPacket() {
  Sample oldest = {};
  if (xQueuePeek(sampleQueue, &oldest, 0) != pdTRUE) {
    return false;
  }

  const size_t payloadLimit = currentBlePayloadLimit();
  const size_t minimumPacketBytes = BLE_PACKET_HEADER_BYTES +
                                    EMG_PACKET_METADATA_BYTES +
                                    EMG_SAMPLE_BYTES;
  if (payloadLimit < minimumPacketBytes) {
    if (!bleMtuErrorReported) {
      Serial.printf("# ERROR,BLE_MTU_TOO_SMALL,mtu=%u,required=%u\r\n",
                    static_cast<unsigned>(blePeerMtu),
                    static_cast<unsigned>(minimumPacketBytes + 3));
      bleMtuErrorReported = true;
    }
    return false;
  }
  bleMtuErrorReported = false;

  const size_t maximumRecords =
      (payloadLimit - BLE_PACKET_HEADER_BYTES -
       EMG_PACKET_METADATA_BYTES) /
      EMG_SAMPLE_BYTES;
  const size_t availableRecords = uxQueueMessagesWaiting(sampleQueue);
  if (availableRecords < maximumRecords &&
      static_cast<uint32_t>(micros() - oldest.timestampUs) <
          EMG_BATCH_WAIT_US) {
    return false;
  }
  const size_t requestedRecords =
      availableRecords < maximumRecords ? availableRecords : maximumRecords;

  uint8_t packet[BLE_MAX_ATT_PAYLOAD_BYTES] = {0};
  size_t offset = BLE_PACKET_HEADER_BYTES;
  putU32(packet, offset, oldest.sequence);
  putU32(packet, offset, oldest.timestampUs);
  putU24(packet, offset, oldest.status);
  putU32(packet, offset, oldest.dropped);
  uint8_t packedRecords = 0;
  for (size_t index = 0; index < requestedRecords; ++index) {
    Sample candidate = {};
    if (xQueuePeek(sampleQueue, &candidate, 0) != pdTRUE ||
        candidate.sequence != oldest.sequence + packedRecords) {
      break;
    }
    Sample sample = {};
    if (xQueueReceive(sampleQueue, &sample, 0) != pdTRUE) {
      break;
    }
    for (uint8_t channel = 0; channel < ADS_CHANNEL_COUNT; ++channel) {
      putI24(packet, offset, sample.channels[channel]);
    }
    ++packedRecords;
  }
  if (packedRecords == 0) {
    return false;
  }

  putBleHeader(packet, BLE_RECORD_TYPE_EMG, packedRecords,
               static_cast<uint8_t>(EMG_SAMPLE_BYTES),
               nextBlePacketSequence);
  return notifyBlePacket(packet, offset);
}

bool drainOneBleImuPacket() {
  ImuSample oldest = {};
  if (xQueuePeek(imuQueue, &oldest, 0) != pdTRUE) {
    return false;
  }

  const size_t payloadLimit = currentBlePayloadLimit();
  const size_t minimumPacketBytes = BLE_PACKET_HEADER_BYTES +
                                    IMU_PACKET_METADATA_BYTES +
                                    IMU_SAMPLE_BYTES;
  if (payloadLimit < minimumPacketBytes) {
    return false;
  }
  const size_t maximumRecords =
      (payloadLimit - BLE_PACKET_HEADER_BYTES -
       IMU_PACKET_METADATA_BYTES) /
      IMU_SAMPLE_BYTES;
  const size_t availableRecords = uxQueueMessagesWaiting(imuQueue);
  if (availableRecords < maximumRecords &&
      static_cast<uint32_t>(micros() - oldest.timestampUs) <
          IMU_BATCH_WAIT_US) {
    return false;
  }
  const size_t requestedRecords =
      availableRecords < maximumRecords ? availableRecords : maximumRecords;

  uint8_t packet[BLE_MAX_ATT_PAYLOAD_BYTES] = {0};
  size_t offset = BLE_PACKET_HEADER_BYTES;
  putU32(packet, offset, oldest.sequence);
  putU32(packet, offset, oldest.timestampUs);
  putU32(packet, offset, oldest.dropped);
  uint8_t packedRecords = 0;
  for (size_t index = 0; index < requestedRecords; ++index) {
    ImuSample candidate = {};
    if (xQueuePeek(imuQueue, &candidate, 0) != pdTRUE ||
        candidate.sequence != oldest.sequence + packedRecords) {
      break;
    }
    ImuSample sample = {};
    if (xQueueReceive(imuQueue, &sample, 0) != pdTRUE) {
      break;
    }
    for (uint8_t axis = 0; axis < 3; ++axis) {
      putI16(packet, offset, sample.acceleration[axis]);
    }
    for (uint8_t axis = 0; axis < 3; ++axis) {
      putI16(packet, offset, sample.gyro[axis]);
    }
    putI16(packet, offset, sample.temperature);
    ++packedRecords;
  }
  if (packedRecords == 0) {
    return false;
  }

  putBleHeader(packet, BLE_RECORD_TYPE_IMU, packedRecords,
               static_cast<uint8_t>(IMU_SAMPLE_BYTES),
               nextBlePacketSequence);
  return notifyBlePacket(packet, offset);
}

void initializeBle() {
  BLEDevice::init(BLE_DEVICE_NAME);
  BLEDevice::setMTU(247);
  BLEDevice::setPower(ESP_PWR_LVL_N6);

  bleServer = BLEDevice::createServer();
  bleServer->setCallbacks(&bleServerCallbacks);

  BLEService *service = bleServer->createService(BLE_SERVICE_UUID);
  bleDataCharacteristic = service->createCharacteristic(
      BLE_DATA_CHARACTERISTIC_UUID, BLECharacteristic::PROPERTY_NOTIFY);
  bleDataCharacteristic->setCallbacks(&bleDataCallbacks);
  bleDataCharacteristic->addDescriptor(new BLE2902());
  service->start();

  BLEAdvertising *advertising = bleServer->getAdvertising();
  advertising->addServiceUUID(BLE_SERVICE_UUID);
  advertising->setScanResponse(true);
  advertising->setMinPreferred(0x06);
  advertising->setMaxPreferred(0x12);
  const String bleAddress = BLEDevice::getAddress().toString();
  const bool advertisingStarted = advertising->start();
  const bool advertisingActive = advertising->isAdvertising();
  Serial.printf(
      "# INFO,BLE_ADVERTISING,name=%s,address=%s,started=%u,active=%u\r\n",
      BLE_DEVICE_NAME, bleAddress.c_str(),
      static_cast<unsigned>(advertisingStarted),
      static_cast<unsigned>(advertisingActive));
  if (!advertisingStarted || !advertisingActive) {
    Serial.println("# ERROR,BLE_ADVERTISING_START");
  }
}

void acquisitionTask(void *parameter) {
  (void)parameter;

  while (true) {
    const uint32_t events = ulTaskNotifyTake(pdTRUE, portMAX_DELAY);
    if (events > 1) {
      const uint32_t missed = events - 1;
      droppedSamples += missed;
      nextSequence += missed;
    }

    uint8_t frame[ADS_FRAME_BYTES] = {0};
    readDataFrame(frame);

    Sample sample = {};
    sample.sequence = nextSequence++;
    sample.timestampUs = micros();
    sample.status = decodeStatus24(frame);
    for (uint8_t channel = 0; channel < ADS_CHANNEL_COUNT; ++channel) {
      sample.channels[channel] = decodeSigned24(&frame[3 + channel * 3]);
    }
    sample.dropped = droppedSamples;

    if (xQueueSend(sampleQueue, &sample, 0) != pdTRUE) {
      ++droppedSamples;
    }

    Lsm6dsoxRawSample rawImu = {};
    if (imu.readIfReady(rawImu)) {
      ImuSample imuSample = {};
      imuSample.sequence = nextImuSequence++;
      imuSample.timestampUs = micros();
      imuSample.temperature = rawImu.temperature;
      for (uint8_t axis = 0; axis < 3; ++axis) {
        imuSample.gyro[axis] = rawImu.gyro[axis];
        imuSample.acceleration[axis] = rawImu.acceleration[axis];
      }
      imuSample.dropped = droppedImuSamples;
      if (xQueueSend(imuQueue, &imuSample, 0) != pdTRUE) {
        ++droppedImuSamples;
      }
    }
    ++acquisitionHeartbeat;
  }
}
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
void loop() {
  if (!streaming) {
    delay(100);
    return;
  }

  if (bleFlushRequested) {
    xQueueReset(sampleQueue);
    xQueueReset(imuQueue);
    bleFlushRequested = false;
  }

  bool packetSent = false;
  if (bleConnected && bleSubscribed) {
    packetSent = drainOneBleEmgPacket();
    packetSent = drainOneBleImuPacket() || packetSent;
  }
  if (!packetSent) {
    delay(1);
  }

  const uint32_t nowMs = millis();
  if (nowMs - lastHeartbeatCheckMs >= 1000) {
    const uint32_t currentHeartbeat = acquisitionHeartbeat;
    if (currentHeartbeat == lastHeartbeat) {
      Serial.println("# ERROR,DRDY_TIMEOUT");
    }
    lastHeartbeat = currentHeartbeat;
    lastHeartbeatCheckMs = nowMs;
  }
}

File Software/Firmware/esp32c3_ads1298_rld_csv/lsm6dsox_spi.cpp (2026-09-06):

#include "lsm6dsox_spi.h"

namespace {
constexpr uint8_t LSM6DSOX_ID = 0x6C;

constexpr uint8_t REG_WHO_AM_I = 0x0F;
constexpr uint8_t REG_CTRL1_XL = 0x10;
constexpr uint8_t REG_CTRL2_G = 0x11;
constexpr uint8_t REG_CTRL3_C = 0x12;
constexpr uint8_t REG_STATUS = 0x1E;
constexpr uint8_t REG_OUT_TEMP_L = 0x20;

constexpr uint8_t CTRL1_XL_104HZ_4G = 0x48;
constexpr uint8_t CTRL2_G_104HZ_500DPS = 0x44;
constexpr uint8_t CTRL3_C_BDU_IF_INC = 0x44;
constexpr uint8_t CTRL3_C_SW_RESET = 0x01;

constexpr uint8_t STATUS_XLDA = 0x01;
constexpr uint8_t STATUS_GDA = 0x02;
constexpr uint8_t SPI_READ = 0x80;
constexpr uint32_t RESET_TIMEOUT_MS = 100;

int16_t decodeSigned16(const uint8_t *bytes) {
  const uint16_t value = static_cast<uint16_t>(bytes[0]) |
                         (static_cast<uint16_t>(bytes[1]) << 8);
  return static_cast<int16_t>(value);
}
}  // namespace

Lsm6dsoxSpi::Lsm6dsoxSpi(SPIClass &spi, uint8_t chipSelectPin)
    : spi_(spi),
      chipSelectPin_(chipSelectPin),
      settings_(1000000, MSBFIRST, SPI_MODE3) {}

bool Lsm6dsoxSpi::begin(uint8_t &deviceId) {
  pinMode(chipSelectPin_, OUTPUT);
  digitalWrite(chipSelectPin_, HIGH);
  delay(10);

  deviceId = readRegister(REG_WHO_AM_I);
  if (deviceId != LSM6DSOX_ID) {
    return false;
  }

  writeRegister(REG_CTRL3_C, CTRL3_C_SW_RESET);
  const uint32_t resetStartMs = millis();
  while ((readRegister(REG_CTRL3_C) & CTRL3_C_SW_RESET) != 0) {
    if (millis() - resetStartMs >= RESET_TIMEOUT_MS) {
      return false;
    }
    delay(1);
  }

  writeRegister(REG_CTRL3_C, CTRL3_C_BDU_IF_INC);
  writeRegister(REG_CTRL1_XL, CTRL1_XL_104HZ_4G);
  writeRegister(REG_CTRL2_G, CTRL2_G_104HZ_500DPS);
  delay(20);

  return readRegister(REG_CTRL3_C) == CTRL3_C_BDU_IF_INC &&
         readRegister(REG_CTRL1_XL) == CTRL1_XL_104HZ_4G &&
         readRegister(REG_CTRL2_G) == CTRL2_G_104HZ_500DPS;
}

bool Lsm6dsoxSpi::readIfReady(Lsm6dsoxRawSample &sample) {
  const uint8_t status = readRegister(REG_STATUS);
  if ((status & (STATUS_XLDA | STATUS_GDA)) != (STATUS_XLDA | STATUS_GDA)) {
    return false;
  }

  uint8_t bytes[14] = {0};
  readRegisters(REG_OUT_TEMP_L, bytes, sizeof(bytes));
  sample.temperature = decodeSigned16(&bytes[0]);
  for (uint8_t axis = 0; axis < 3; ++axis) {
    sample.gyro[axis] = decodeSigned16(&bytes[2 + axis * 2]);
    sample.acceleration[axis] = decodeSigned16(&bytes[8 + axis * 2]);
  }
  return true;
}

uint8_t Lsm6dsoxSpi::readRegister(uint8_t address) {
  uint8_t value = 0;
  readRegisters(address, &value, 1);
  return value;
}

void Lsm6dsoxSpi::writeRegister(uint8_t address, uint8_t value) {
  spi_.beginTransaction(settings_);
  digitalWrite(chipSelectPin_, LOW);
  delayMicroseconds(1);
  spi_.transfer(address & ~SPI_READ);
  spi_.transfer(value);
  delayMicroseconds(1);
  digitalWrite(chipSelectPin_, HIGH);
  spi_.endTransaction();
}

void Lsm6dsoxSpi::readRegisters(uint8_t address, uint8_t *data, size_t length) {
  spi_.beginTransaction(settings_);
  digitalWrite(chipSelectPin_, LOW);
  delayMicroseconds(1);
  spi_.transfer(address | SPI_READ);
  for (size_t index = 0; index < length; ++index) {
    data[index] = spi_.transfer(0x00);
  }
  delayMicroseconds(1);
  digitalWrite(chipSelectPin_, HIGH);
  spi_.endTransaction();
}

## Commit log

2026-09-06 Initial release of wearable sEMG-IMU gesture recognition system
    [Electrode-strap and Extension.f3d, PCB and Battery Enclosure and Lid.f3d, PCB-Strap.f3d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]
2026-09-09 Add multimodal ablation experiments
    [aggregate_summary.csv, history.csv, run_summary.csv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]
